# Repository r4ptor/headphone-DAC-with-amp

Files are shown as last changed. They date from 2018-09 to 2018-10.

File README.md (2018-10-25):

# Portable headphone DAC with amplifier stage

A simple and portable audio digital to analogue converter with amplifying abilities.

## Structure

The Texas Instruments PCM2707 serves as the USB interface. This interface provides a clock and I2S signal for the main Hifi
digital to analogue converter, the PCM1794A.

Since this converter needs a 3.3V power source a LP5907 ultra-low-noise LDO is being used to
generate the desired voltage.

The DAC provides a differential output current. This is being feeded into a two opamps that are used as transimpedance amplifiers which convert the DAC output current into a differential voltage. Then a difference amplifier converts this differential voltage to single-ended. For this the TI reference design [TIDU672C](http://www.ti.com/litv/pdf/tidu672c) was used. Therefore the Amplifier stage consists as two OPA1612 and a OPA1622.

A LM2662M switched capacitor voltage converter generates the necessary -5V to supply the operational amplifiers with +-5V.

The project is realized with the open source EDA tool [KiCad](https://kicad-pcb.org/).

With the current parts the whole project costs around 45€ at [Digikey](https://www.digikey.com/). For details have a look at the [BOM.csv](https://github.com/r4ptor/headphone-DAC-with-amp/blob/master/BOM.csv) or [BOM.html](https://github.com/r4ptor/headphone-DAC-with-amp/blob/master/BOM.html).

## Datasheets of used components
[PCM2707](https://www.ti.com/lit/ds/symlink/pcm2706.pdf) USB Interface

[PCM1794A](http://www.ti.com/lit/ds/symlink/pcm1794a.pdf) 24-Bit, 192-kHz audio DAC

[LP5907](http://www.ti.com/lit/ds/symlink/lp5907.pdf) Low-noise LDO

[LM2662M](http://www.ti.com/lit/ds/symlink/lm2662.pdf) Voltage converter

[OPA1612](http://www.ti.com/lit/ds/symlink/opa1612.pdf) Operational amplifier

[OPA1622](http://www.ti.com/lit/ds/symlink/opa1622.pdf) Operational amplifier

## Rendered picture of the current PCB layout

Note: old design!
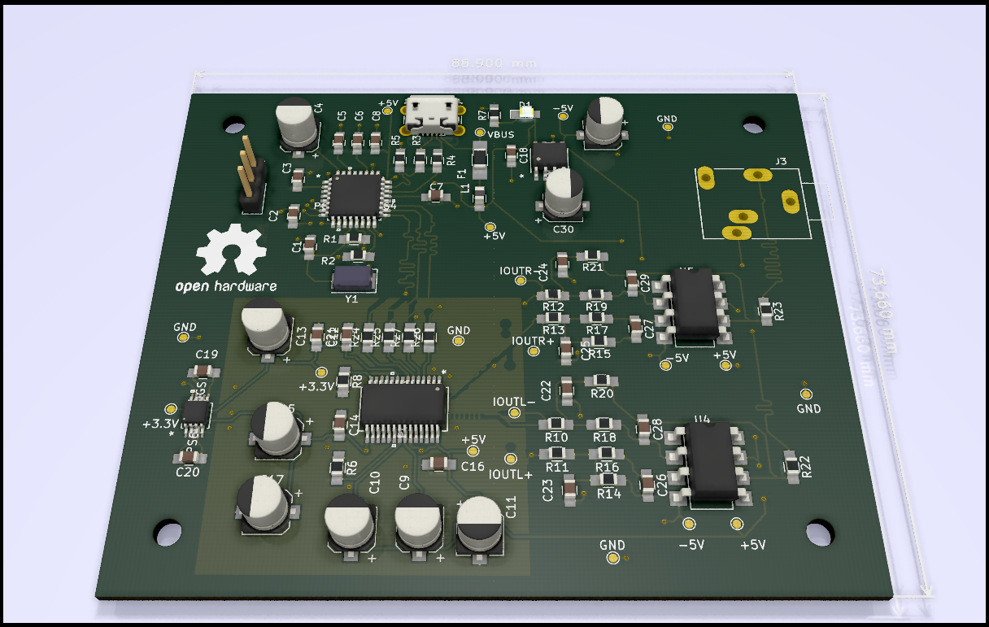
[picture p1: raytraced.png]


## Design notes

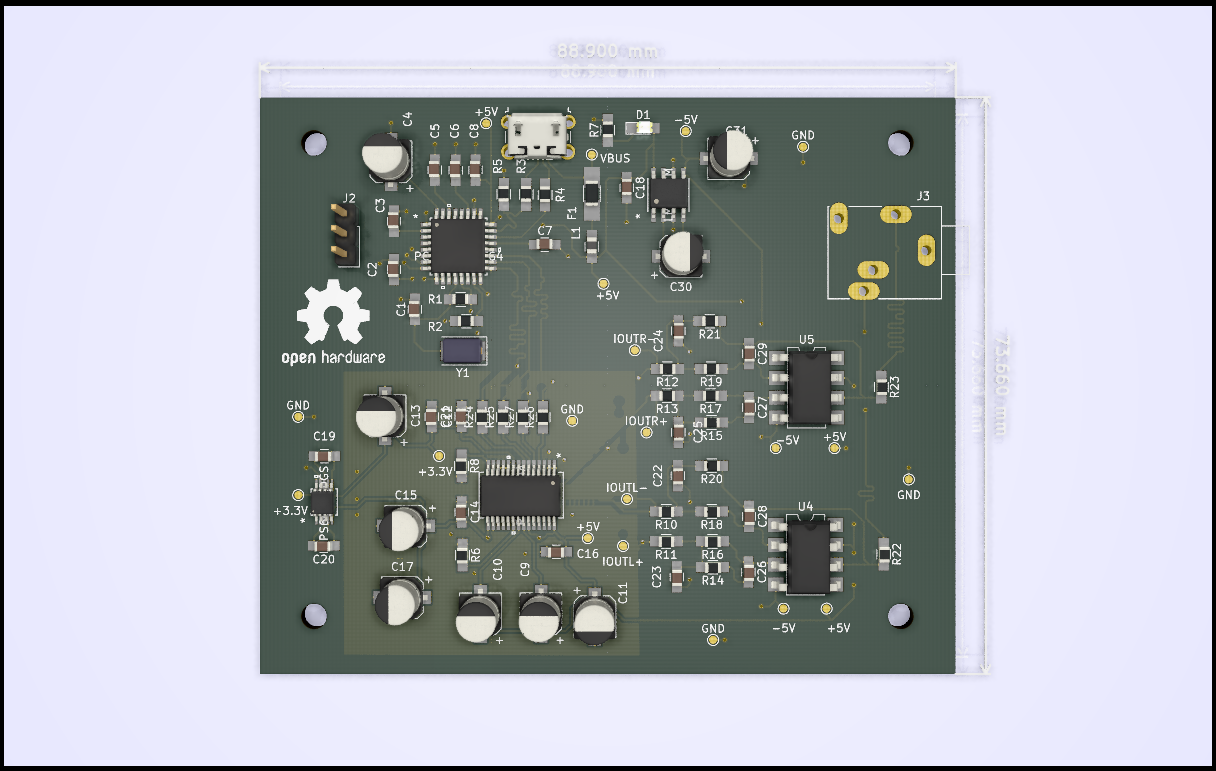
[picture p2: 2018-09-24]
pictures/headphone_dac_with_amp_v2_top_3d.png

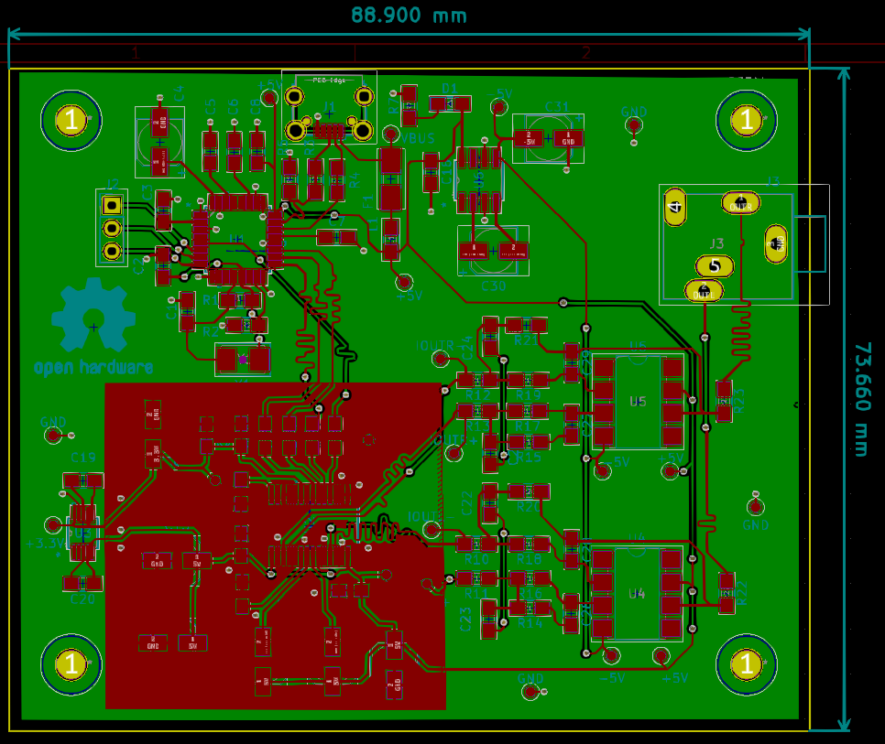
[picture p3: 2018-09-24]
pictures/headphone_dac_with_amp_v2_top_filled.png

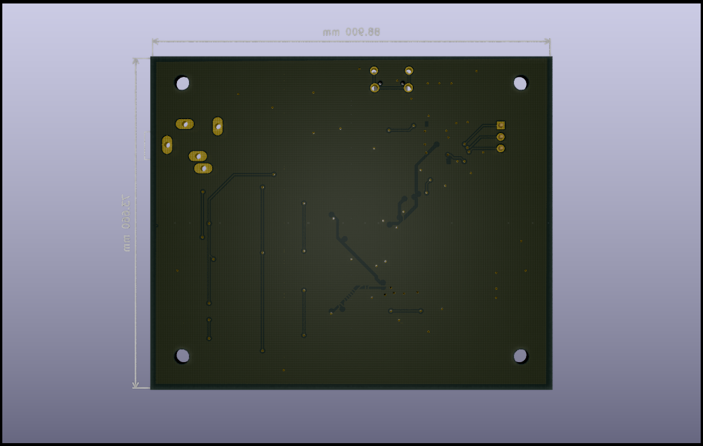
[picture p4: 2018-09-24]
pictures/headphone_dac_with_amp_v2_bot_3d.png

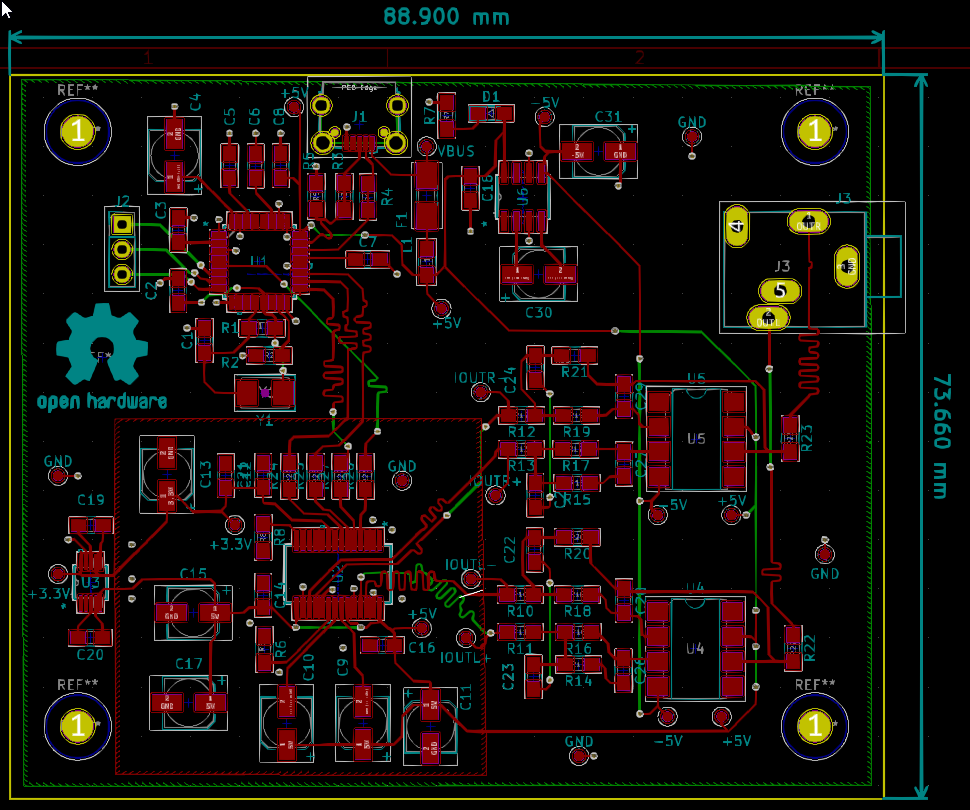
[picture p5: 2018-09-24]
pictures/headphone_dac_with_amp_v2_top.png

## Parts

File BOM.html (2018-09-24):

Source File | F:\nextcloud\eagle_projects\headphone_dac_with_amp_v2\headphone_amp_v2.sch
BoM Date | 23/09/2018 17:00:56
Schematic Version | 0.2
Schematic Date | 2018-09-20
KiCad Version | Eeschema (5.0.0)
Component Groups | 30
Component Count (per PCB) | 70
Fitted Components (per PCB) | 70
Number of PCBs | 1
Total Component Count (for 1 PCBs) | 70
 | Description | Part | References | Value | Footprint | Quantity Per PCB | Datasheet | Part number | Note
1 | Unpolarized capacitor | C | C12 C14 C16 | 0.1uF | C_0805_HandSoldering | 3 | http://media.digikey.com/pdf/Data%20Sheets/Samsung%20PDFs/CL_Series_MLCC_ds.pdf | CL21F104ZBCNNNC
2 | Polarised capacitor | CP1 | C4 C11 C13 C15 C17 | 10uF | CP_Elec_5x5.8 | 5 | https://industrial.panasonic.com/cdbs/www-data/pdf/RDE0000/ABA0000C1145.pdf | EEE-1VA100SR
3 | Unpolarized capacitor | C | C21 | 10uF | C_0805_HandSoldering | 1 | http://www.samsungsem.com/kr/support/product-search/mlcc/CL21A106KPFNNNG.jsp | CL21A106KPFNNNG
4 | Unpolarized capacitor | C | C26 C27 C28 C29 | 1nF | C_0805_HandSoldering | 4 | http://www.samsungsem.com/kr/support/product-search/mlcc/CL21C010CBANNNC.jsp | CL21C010CBANNNC
5 | Unpolarized capacitor | C | C3 C5 C6 C7 C8 C19 C20 | 1uF | C_0805_HandSoldering | 7 | http://www.yageo.com/documents/recent/UPY-GPHC_X7R_6.3V-to-50V_18.pdf | CC0805KKX7R6BB105
6 | Unpolarized capacitor | C | C18 | 2.2uF | C_0805_HandSoldering | 1 | https://api.kemet.com/component-edge/download/datasheet/C0805C225K8RACTU.pdf | C0805C225K8RACTU
7 | Unpolarized capacitor | C | C1 C2 | 22pF | C_0805_HandSoldering | 2 | https://4donline.ihs.com/images/VipMasterIC/IC/AVXC/AVXC-S-A0001944187/AVXC-S-A0001944187-1.pdf | 08051A220KAT2A
8 | Unpolarized capacitor | C | C22 C23 C24 C25 | 4.7nF | C_0805_HandSoldering | 4 | https://api.kemet.com/component-edge/download/datasheet/C0805C472KARECAUTO.pdf | C0805C472KARECAUTO
9 | Polarised capacitor | CP1 | C9 C10 C30 C31 | 47uF | CP_Elec_5x5.3 | 4 | https://industrial.panasonic.com/cdbs/www-data/pdf/RDE0000/ABA0000C1145.pdf | EEE-1CA470WR | Low ESR
10 | LED generic | LED | D1 | LED blue | LED_0805_HandSoldering | 1 | http://optoelectronics.liteon.com/upload/download/DS-22-99-0226/LTST-C170TBKT.pdf | LTST-C170TBKT
11 | resettable fuse, polymeric positive temperature coefficient (PPTC) | Polyfuse | F1 | Polyfuse | Fuse_SMD1206_HandSoldering | 1 | https://belfuse.com/resources/datasheets/circuitprotection/ds-cp-c1t-series.pdf | 0685T2500-01
12 | Audio Jack, 3 Poles (Stereo / TRS), Grounded Sleeve | AudioJack3_Ground | J3 | AudioJack3_Ground | Stereo_Jack_3.5mm_Switch_Ledino_KB3SPRS | 1 | https://www.cui.com/product/resource/digikeypdf/sj1-352xn_series.pdf
13 | Generic connector, single row, 01x03, script generated (kicad-library-utils/schlib/autogen/connector/) | Conn_01x03_Male | J2 | HID_JMP | Pin_Header_Straight_1x03_Pitch2.54mm | 1 | ~ | SJ1-3523N
14 | USB mini/micro connector | USB_OTG | J1 | USB_OTG | USB_Micro-B_Wuerth-629105150521_CircularHoles | 1 | https://katalog.we-online.de/em/datasheet/629105150521.pdf | 629105150521
15 | Ferrite bead | Ferrite_Bead | L1 | 1A | L_0805_HandSoldering | 1 | http://ds.yuden.co.jp/TYCOMPAS/ut/detail.do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 | BK2125HS470-T
16 | Resistor | R | R16 R17 R18 R19 | 1.02k | R_0805_HandSoldering | 4 | https://industrial.panasonic.com/cdbs/www-data/pdf/RDM0000/AOA0000C307.pdf | ERA-6AEB1021V
17 | Resistor | R | R2 R5 | 1.5k | R_0805_HandSoldering | 2 | https://www.seielect.com/Catalog/SEI-rncp.pdf | RNCP0805FTD1K50
18 | Resistor | R | R24 R25 R26 | 10R | R_0805_HandSoldering | 3 | https://www.seielect.com/Catalog/SEI-rncp.pdf | RNCP0805FTD10R0
19 | Resistor | R | R6 R8 | 10k | R_0805_HandSoldering | 2 | https://www.seielect.com/Catalog/SEI-RNCF.pdf | RNCF0805DTE10K0
20 | Resistor | R | R1 | 1M | R_0805_HandSoldering | 1 | https://industrial.panasonic.com/cdbs/www-data/pdf/RDM0000/AOA0000C307.pdf | ERA-6AEB105V
21 | Resistor | R | R3 R4 R22 R23 | 22R | R_0805_HandSoldering | 4 | http://www.yageo.com/documents/recent/PYu-RC_Group_51_RoHS_L_9.pdf | RC0805FR-0722RL
22 | Resistor | R | R27 | 47R | R_0805_HandSoldering | 1 | https://industrial.panasonic.com/cdbs/www-data/pdf/RDA0000/AOA0000C304.pdf | ERJ-6ENF47R0V
23 | Resistor | R | R7 | 560R | R_0805_HandSoldering | 1 | https://www.seielect.com/Catalog/SEI-RMCF_RMCP.pdf | RMCF0805JT560R
24 | Resistor | R | R10 R11 R12 R13 R14 R15 R20 R21 | 887R | R_0805_HandSoldering | 8 | http://www.yageo.com/documents/recent/PYu-RC_Group_51_RoHS_L_9.pdf | RC0805FR-07887RL
25 |  | LM2662M | U6 | LM2662M | LM2662M | 1 | http://www.ti.com/lit/ds/symlink/lm2662.pdf | LM2662M/NOPB
26 |  | OPA2134PA | U4 U5 | OPA2134PA | SMDIP-8_W7.62mm | 2 | http://www.ti.com/lit/ds/symlink/opa2134.pdf | OPA2134PA
27 | 24-Bit, 192-kHz Sampling, Advanced Segment, Audio Stereo Digital-to-Analog Converter, HW Control, SSOP-28 | PCM1794A | U2 | PCM1794A | PCM1794ADBG4 | 1 | http://www.ti.com/lit/ds/symlink/pcm1794a.pdf | PCM1794ADBR
28 |  | PCM2707PJTG4 | U1 | PCM2707PJTG4 | PCM2707PJTG4 | 1 | http://www.ti.com/lit/ds/symlink/pcm2706.pdf | PCM2707CPJT
29 | 250mA High-Efficiency Step-Down Charge Pump Regulator, 3.3V Output Voltage, MSOP-10 | TPS60501DGS | U3 | TPS60501DGS | TPS60501DGSG4 | 1 | http://www.ti.com/lit/ds/symlink/tps60503.pdf | TPS60501DGSR
30 | Two pin crystal | Crystal | Y1 | 12Mhz | Crystal_SMD_5032-2pin_5.0x3.2mm | 1 | https://media.digikey.com/pdf/Data%20Sheets/AVX%20PDFs/CX5032GB_(CX-53F)_DS.pdf | CX5032GB12000H0PESZZ

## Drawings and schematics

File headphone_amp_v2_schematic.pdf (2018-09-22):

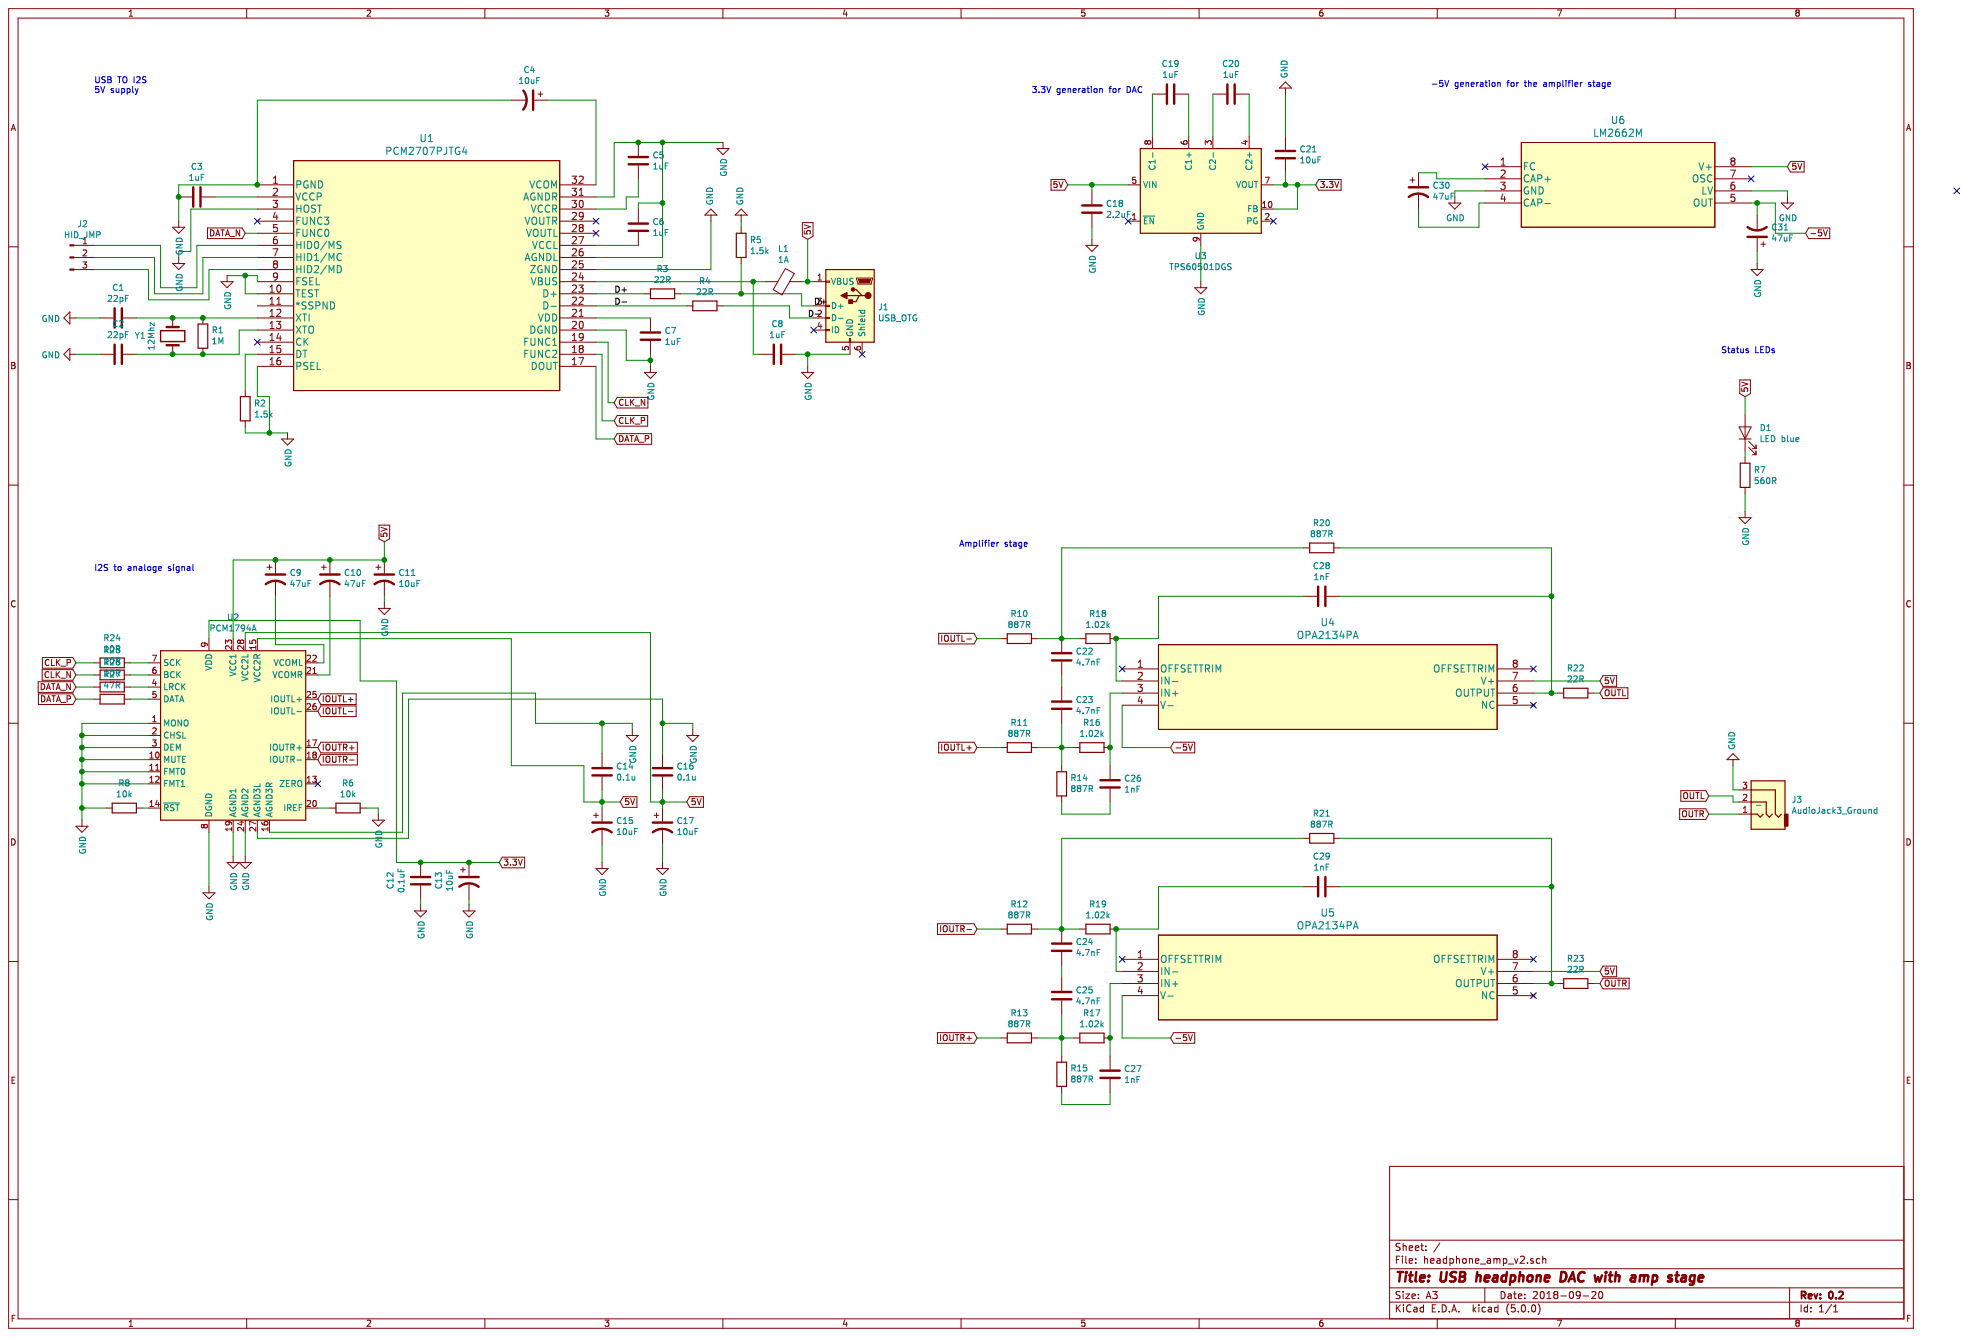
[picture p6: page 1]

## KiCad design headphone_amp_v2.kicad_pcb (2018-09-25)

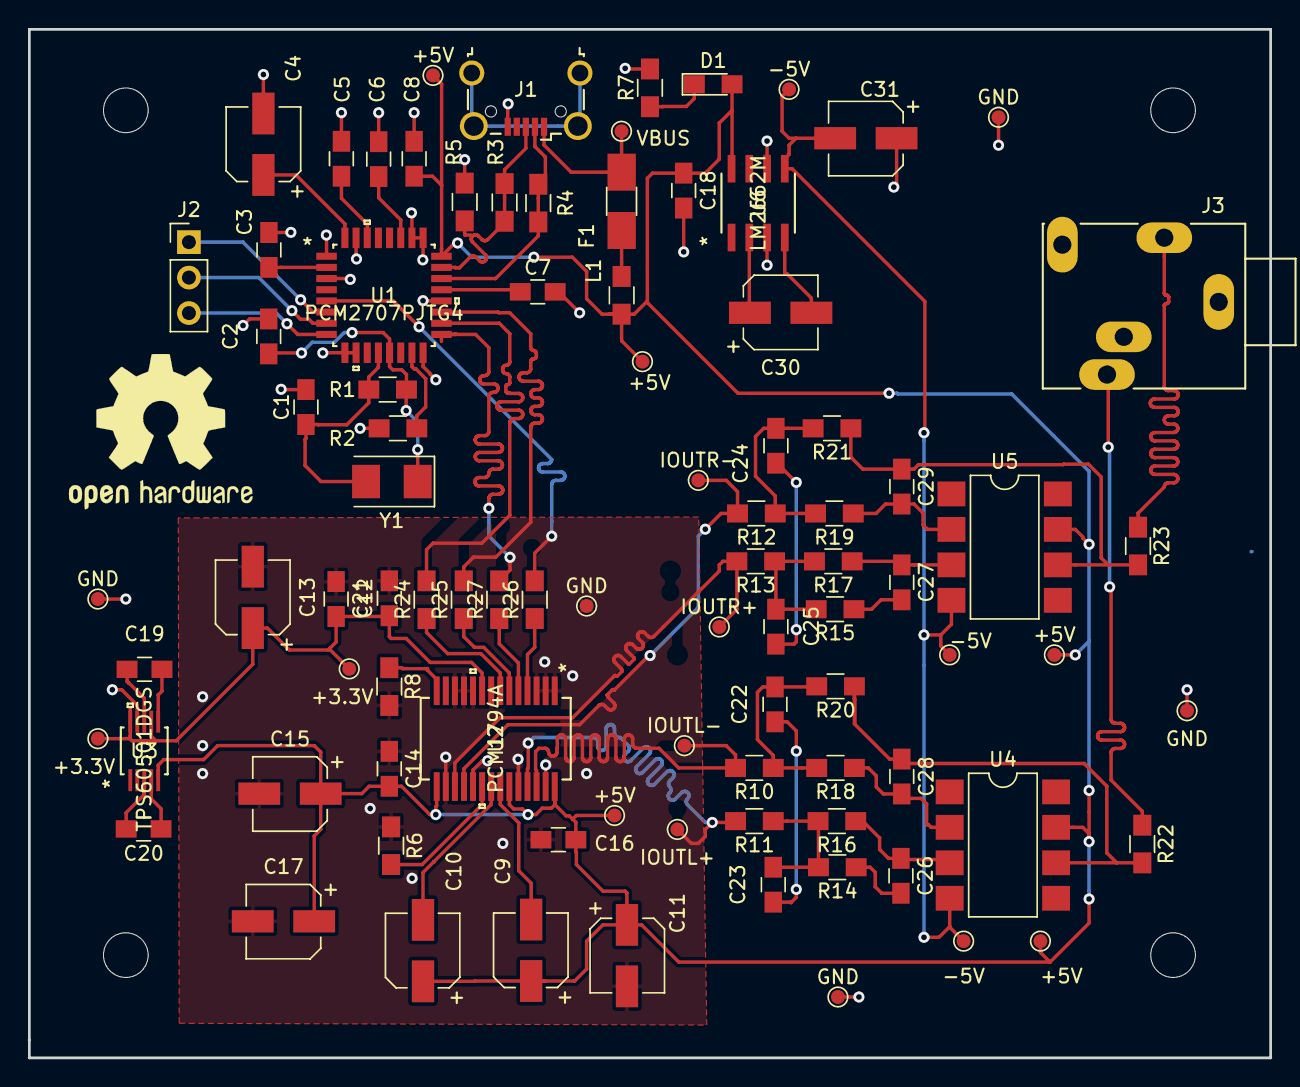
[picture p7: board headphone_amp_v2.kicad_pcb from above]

Board: 2 copper layers, 88.9 x 73.7 mm, 90 parts (0 on the bottom side), 58 nets.

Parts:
+3.3V, +3.3V#2, +5V, +5V#2, +5V#3, +5V#4, +5V#5: TestPoint_Pad_D1.0mm
-5V, -5V#2, -5V#3: TestPoint_Pad_D1.0mm
C1, C2: 22pF; C_0805_HandSoldering
C3, C5, C6, C7, C8, C19, C20: 1uF; C_0805_HandSoldering
C4, C13: 10uF; CP_Elec_5x5.8
C9, C10, C30, C31: 47uF; CP_Elec_5x5.3
C11, C15, C17: 10uF; CP_Elec_5x5.3
C12, C14, C16: 0.1uF; C_0805_HandSoldering
C18: 2.2uF; C_0805_HandSoldering
C21: 10uF; C_0805_HandSoldering
C22, C23, C24, C25: 4.7nF; C_0805_HandSoldering
C26, C27, C28, C29: 1nF; C_0805_HandSoldering
D1: LED blue; LED_0805_HandSoldering
F1: Polyfuse; Fuse_SMD1206_HandSoldering
GND: TestPoint_Pad_D1.0mm
GND#2, GND#3, GND#4, GND#5: TestPoint_Pad_D1.0mm
IOUTL+: TestPoint_Pad_D1.0mm
IOUTL-: TestPoint_Pad_D1.0mm
IOUTR+: TestPoint_Pad_D1.0mm
IOUTR-: TestPoint_Pad_D1.0mm
J1: USB_OTG; USB_Micro-B_Wuerth-629105150521_CircularHoles
J2: HID_JMP; Pin_Header_Straight_1x03_Pitch2.54mm
J3: AudioJack3_Ground; Stereo_Jack_3.5mm_Switch_Ledino_KB3SPRS
L1: 1A; L_0805_HandSoldering
R1: 1M; R_0805_HandSoldering
R2, R5: 1.5k; R_0805_HandSoldering
R3, R4, R22, R23: 22R; R_0805_HandSoldering
R6, R8: 10k; R_0805_HandSoldering
R7: 560R; R_0805_HandSoldering
R10, R11, R12, R13, R14, R15, R20, R21: 887R; R_0805_HandSoldering
R16, R17, R18, R19: 1.02k; R_0805_HandSoldering
R24, R25, R26: 10R; R_0805_HandSoldering
R27: 47R; R_0805_HandSoldering
U1: PCM2707PJTG4
U2: PCM1794A; PCM1794ADBG4
U3: TPS60501DGS; TPS60501DGSG4
U4, U5: OPA2134PA; SMDIP-8_W7.62mm
U6: LM2662M
VBUS: TestPoint_Pad_D1.0mm
Y1: 12Mhz; Crystal_SMD_5032-2pin_5.0x3.2mm

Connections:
3.3V: +3.3V.1, +3.3V#2.1, C12.1, C13.1, C21.2, U2.9, U3.7, U3.10
5V: +5V.1, +5V#2.1, +5V#3.1, +5V#4.1, +5V#5.1, C8.2, C9.1, C10.1, C11.1, C14.2, C15.1, C16.2, C17.1, C18.1, D1.2, L1.2, U1.24, U2.15, U2.23, U2.28, U3.5, U4.7, U5.7, U6.8
-5V: -5V.1, -5V#2.1, -5V#3.1, C31.2, U4.4, U5.4, U6.5
/D+: J1.3, R3.1, R3.2, R5.2, U1.23
/D-: J1.2, R4.1, R4.2, U1.22
CLK_N: R25.2, U1.19
CLK_P: R24.2, U1.18
DATA_N: R26.2, U1.5
DATA_P: R27.2, U1.17
GND: C1.2, C2.2, C3.2, C4.2, C5.1, C6.1, C7.2, C8.1, C11.2, C12.2, C13.2, C14.1, C15.2, C16.1, C17.2, C18.2, C21.1, C31.1, GND.1, GND#2.1, GND#3.1, GND#4.1, GND#5.1, J1.5, J3.3, R2.2, R5.1, R6.1, R7.2, R8.2, U1.1, U1.3, U1.9, U1.10, U1.16, U1.20, U1.25, U1.26, U1.31, U2.1, U2.2, U2.3, U2.8, U2.10, U2.11, U2.12, U2.16, U2.19, U2.24, U2.27, U3.9, U6.3, U6.6
IOUTL+: IOUTL+.1, R11.2, U2.25
IOUTL-: IOUTL-.1, R10.2, U2.26
IOUTR+: IOUTR+.1, R13.2, U2.17
IOUTR-: IOUTR-.1, R12.2, U2.18
unnamed: C1.1, R1.2, U1.12, Y1.2
unnamed: C2.1, R1.1, U1.13, Y1.1
unnamed: C3.1, U1.2
unnamed: C4.1, U1.32
unnamed: C5.2, U1.30
unnamed: C6.2, U1.27
unnamed: C7.1, U1.21
unnamed: C9.2, U2.22
unnamed: C10.2, U2.21
unnamed: C19.1, U3.6
unnamed: C19.2, U3.8
unnamed: C20.1, U3.4
unnamed: C20.2, U3.3
unnamed: C22.1, R10.1, R18.2, R20.2
unnamed: C22.2, C23.1
unnamed: C23.2, R11.1, R14.2, R16.2
unnamed: C24.1, R12.1, R19.2, R21.2
unnamed: C24.2, C25.1
unnamed: C25.2, R13.1, R15.2, R17.2
unnamed: C26.1, R16.1, U4.3
unnamed: C26.2, R14.1
unnamed: C27.1, R17.1, U5.3
unnamed: C27.2, R15.1
unnamed: C28.1, R20.1, R22.2, U4.6
unnamed: C28.2, R18.1, U4.2
unnamed: C29.1, R21.1, R23.2, U5.6
unnamed: C29.2, R19.1, U5.2
unnamed: C30.1, U6.2
unnamed: C30.2, U6.4
unnamed: D1.1, R7.1
unnamed: F1.1, J1.1, VBUS.3
unnamed: F1.2, L1.1
unnamed: J2.1, U1.6
unnamed: J2.2, U1.7
unnamed: J2.3, U1.8
unnamed: R2.1, U1.15
unnamed: R6.2, U2.20
unnamed: R8.1, U2.14
unnamed: R24.1, U2.7
unnamed: R25.1, U2.6
unnamed: R26.1, U2.4
unnamed: R27.1, U2.5
OUTL: J3.2, R22.1
OUTR: J3.1, R23.1

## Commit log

2018-09-22 initial commit, schematic done, datasheets can be found within the kicad symbols
    [headphone_amp_v2.sch]
2018-09-22 a first version of the layouted board. Not the prettiest but 0 errors in DRC. Raytraced 3D image included
    [headphone_amp_v2.kicad_pcb]
2018-09-22 updated the layout of components and rerouted the traces. The components are grouped more nicely, the board length was reduced by 5mm
    [headphone_amp_v2.kicad_pcb, headphone_amp_v2.sch]
2018-09-22 added mountingholes(m3)
    [headphone_amp_v2.kicad_pcb]
2018-09-22 updated the opamps and crystal to a smd version, removed ground traces in favor of vias
    [headphone_amp_v2.kicad_pcb]
2018-09-22 added a pcb of the schematic and overview pictures
2018-09-22 PCB: Draft update with better component placement
    This moves some components around to reduce via count, improve bypass capacitor layout, and improve manufacturability.
    Additional work needs to be done to clean up the positioning of refdes, duplicate the left audio channel layout.
    [headphone_amp_v2.kicad_pcb]
2018-09-22 added testpads[to be routed], updated rendered images
    [headphone_amp_v2.kicad_pcb, headphone_amp_v2.sch]
2018-09-23 updated board layout as suggested by the reddit community. New rendered pictures added. Polyfuse for VBUS added
    [headphone_amp_v2.kicad_pcb, headphone_amp_v2.sch]
2018-09-23 updated the pictes(silkscreen changed with open hardware logo
2018-09-23 minor changes, HMTL BOM created
    [headphone_amp_v2.kicad_pcb, headphone_amp_v2.sch]
2018-09-23 fixed some footprints, inserted all needed specification sheets, updated the BOM list
    [headphone_amp_v2.kicad_pcb, headphone_amp_v2.sch]
2018-09-23 updated fuse footprint
2018-09-23 added several testpoints and moved some silkscreen component names for visibility
    [headphone_amp_v2.kicad_pcb]
2018-09-24 length matched the signal traces
    [headphone_amp_v2.kicad_pcb]
2018-09-24 updated BOM, generated a *.csv and *.html version. Updated the readme with the total cost
    [BOM.csv]
2018-09-25 fixed a too narrow track to J2
    [headphone_amp_v2.kicad_pcb]
2018-10-25 first draft of the schematic isnt't working. New draft got updated with a different 3.3V converter and different amplifier stage. Amp stag now uses OPA1612 and OPA1622. Amp stage ref design is being 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
    [headphone_amp_v2.sch]
2018-10-25 added all desired values to the compoments
    [headphone_amp_v2.sch]

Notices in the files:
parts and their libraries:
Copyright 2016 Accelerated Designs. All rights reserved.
